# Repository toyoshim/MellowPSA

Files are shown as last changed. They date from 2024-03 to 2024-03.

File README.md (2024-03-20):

# MellowPSA

I/O 1981年6月号に掲載されたPSAを元にして以下の修正を行ったもの

- 入手困難になりつつあるロジックICはまとめてCPLD（MAX7000）で実装した
- RAM制御信号のワンショット化の回路はコンデンサの充電を利用した回路から、同期回路に変更した
- MOVE転送を実行する際、RAM制御だけでなくキャラクターデータ出力もワンショット化した
- 3声化対応のため、I/O 02Hのb6とb7をラッチし、それぞれGATE 1、GATE 2に接続した
- 3声とBEEP音のミックス・増幅回路はM.K WorkshopさんのPSA基板を参考に実装した
- 128キャラクターモートに加え、256キャラクターモードを追加実装した
- OFF、128キャラクターモード、256キャラクターモードはリセットボタンでローテーションで切り替わるように実装した（記事に載っていたリセットボタンでON/OFFにする方法を参考にしている）
- 電源投入時の動作モードを確実にOFFモードに設定するため、電源投入後しばらくLOWに張り付くPON信号をコンデンサのチャージを利用して導入した

注意点
- 現時点でコミットされている基板データはキャラROMの実装位置が2.5ピン分左に寄っているので、新規に作る際には修正してボードを作るべし
- 基板データで用いているSRAMが既に入手困難かもしれない
- そもそもCPLDのMAX7000が入手困難

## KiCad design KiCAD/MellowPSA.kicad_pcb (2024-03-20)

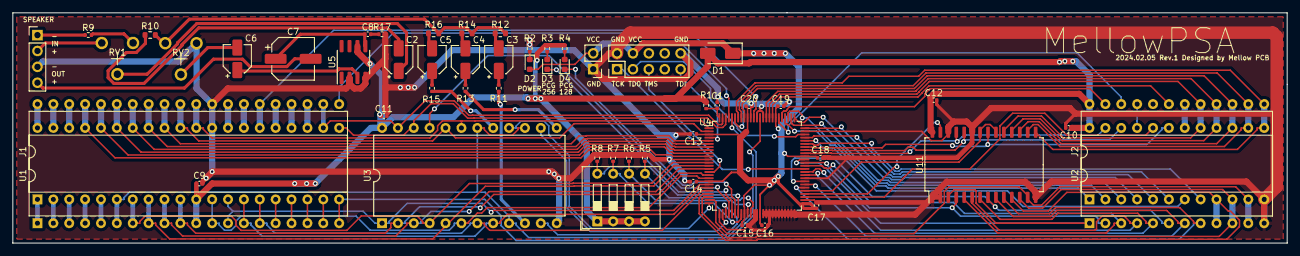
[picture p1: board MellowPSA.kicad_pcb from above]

Board: 2 copper layers, 203.8 x 36.8 mm, 55 parts (0 on the bottom side), 115 nets.

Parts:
C1: 3.3u; C_0402_1005Metric
C2, C3, C4, C5, C6: 10u; CP_Elec_4x5.4
C7: 220u; CP_Elec_6.3x5.4
C8: 0.047u; C_0402_1005Metric
C9, C10, C11, C12, C13, C14, C15, C16, C17, C18, C19, C20: 0.1u; C_0402_1005Metric
D1: D; D_SMA
D2: LED_PWR; LED_0603_1608Metric
D3: LED_256; LED_0603_1608Metric
D4: LED_ON; LED_0603_1608Metric
J1: Z80Socket; DIP-40_W15.24mm
J2: D2716Sock; DIP-24_W15.24mm
J3: JTAG; PinHeader_2x05_P2.54mm_Vertical
J4: PWR; PinHeader_1x02_P2.54mm_Vertical
J5: SP; PinHeader_1x04_P2.54mm_Vertical
R1, R5, R6, R7, R8: 10k; R_0402_1005Metric
R2, R3, R4: 1k; R_0402_1005Metric
R9, R11, R13, R15: 2K; R_0402_1005Metric
R10, R12, R14, R16: 5.6K; R_0603_1608Metric
R17: 10; R_0402_1005Metric
RV1, RV2: 1K; RV-RM-065
SW1: SW_DIP_x04; SW_DIP_SPSTx04_Slide_9.78x12.34mm_W7.62mm_P2.54mm
U1: Z80CPU; DIP-40_W15.24mm
U2: D2716; DIP-24_W15.24mm
U3: 8253; DIP-24_W15.24mm
U4: EPM7128S100(TQFP); TQFP-100_14x14mm_P0.5mm
U5: LM386; SOP-8_3.76x4.96mm_P1.27mm
U11: SRM2B256SLMX; SOIC-28W_8.4x18.7mm_P1.27mm_SRM2B256

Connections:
/A0: J1.30 (A0), U1.30 (A0), U3.19 (A0), U4.1 (I/O)
/A1: J1.31 (A1), U1.31 (A1), U3.20 (A1), U4.2 (I/O)
/A2: J1.32 (A2), U1.32 (A2), U4.5 (I/O)
/A3: J1.33 (A3), U1.33 (A3), U4.6 (I/O)
/A4: J1.34 (A4), U1.34 (A4), U4.7 (I/O)
/A5: J1.35 (A5), U1.35 (A5), U4.8 (I/O)
/A6: J1.36 (A6), U1.36 (A6), U4.9 (I/O)
/A7: J1.37 (A7), U1.37 (A7), U4.10 (I/O)
/A8: J1.38 (A8), U1.38 (A8)
/A9: J1.39 (A9), U1.39 (A9)
/A10: J1.40 (A10), U1.40 (A10)
/A11: J1.1 (A11), U1.1 (A11)
/A12: J1.2 (A12), U1.2 (A12)
/A13: J1.3 (A13), U1.3 (A13)
/A14: J1.4 (A14), U1.4 (A14)
/A15: J1.5 (A15), U1.5 (A15)
/CA0: U2.8, U4.56 (I/O), U11.10 (A0)
/CA1: U2.7, U4.57 (I/O), U11.9 (A1)
/CA2: U2.6, U4.58 (I/O), U11.8 (A2)
/CA3: U2.5, U4.60 (I/O), U11.7 (A3)
/CA4: U2.4, U4.61 (I/O), U11.6 (A4)
/CA5: U2.3, U4.63 (I/O), U11.5 (A5)
/CA6: U2.2, U4.64 (I/O), U11.4 (A6)
/CA7: U2.1, U4.65 (I/O), U11.3 (A7)
/CA8: U2.23, U4.67 (I/O), U11.25 (A8)
/CA9: U2.22, U4.68 (I/O), U11.24 (A9)
/CA10: U2.19, U4.69 (I/O), U11.21 (A10)
/CCS2: J2.18, U2.18
/CCS3: J2.21, U2.21
/CD0: J2.9, U2.9, U4.22 (I/O), U11.11 (D0)
/CD1: J2.10, U2.10, U4.23 (I/O), U11.12 (D1)
/CD2: J2.11, U2.11, U4.24 (I/O), U11.13 (D2)
/CD3: J2.13, U2.13, U4.94 (I/O), U11.15 (D3)
/CD4: J2.14, U2.14, U4.93 (I/O), U11.16 (D4)
/CD5: J2.15, U2.15, U4.92 (I/O), U11.17 (D5)
/CD6: J2.16, U2.16, U4.85 (I/O), U11.18 (D6)
/CD7: J2.17, U2.17, U4.84 (I/O), U11.19 (D7)
/D0: J1.14 (D0), U1.14 (D0), U3.8 (D0), U4.20 (I/O)
/D1: J1.15 (D1), U1.15 (D1), U3.7 (D1), U4.21 (I/O)
/D2: J1.12 (D2), U1.12 (D2), U3.6 (D2), U4.17 (I/O)
/D3: J1.8 (D3), U1.8 (D3), U3.5 (D3), U4.13 (I/O)
/D4: J1.7 (D4), U1.7 (D4), U3.4 (D4), U4.12 (I/O)
/D5: J1.9 (D5), U1.9 (D5), U3.3 (D5), U4.14 (I/O)
/D6: J1.10 (D6), U1.10 (D6), U3.2 (D6), U4.16 (I/O)
/D7: J1.13 (D7), U1.13 (D7), U3.1 (D7), U4.19 (I/O)
/DIPSW0: R5.1, SW1.5, U4.36 (I/O)
/DIPSW1: R6.1, SW1.6, U4.35 (I/O)
/DIPSW2: R7.1, SW1.7, U4.33 (I/O)
/DIPSW3: R8.1, SW1.8, U4.32 (I/O)
/FA0: J2.8, U4.70 (I/O)
/FA1: J2.7, U4.71 (I/O)
/FA2: J2.6, U4.72 (I/O)
/FA3: J2.5, U4.75 (I/O)
/FA4: J2.4, U4.76 (I/O)
/FA5: J2.3, U4.77 (I/O)
/FA6: J2.2, U4.78 (I/O)
/FA7: J2.1, U4.79 (I/O)
/FA8: J2.23, U4.80 (I/O)
/FA9: J2.22, U4.81 (I/O)
/FA10: J2.19, U4.83 (I/O)
/IN+: J5.2, RV1.3
/IN-: J5.1, R9.1
/LED0: D4.1 (K), U4.31 (I/O)
/LED1: D3.1 (K), U4.30 (I/O)
/OUT+: C7.2, J5.4
/PON: C1.2, R1.2, U4.100 (I/O)
/TCK: J3.1, U4.62 (I/O/TCK)
/TDI: J3.9, U4.4 (I/O/TDI)
/TDO: J3.3, U4.73 (I/O/TDO)
/TG0: U3.11 (G0), U4.28 (I/O)
/TG1: U3.14 (G1), U4.27 (I/O)
/TG2: U3.16 (G2), U4.25 (I/O)
/TMS: J3.5, U4.15 (I/O/TMS)
/TO0: R11.1, U3.10 (OUT0)
/TO1: R13.1, U3.13 (OUT1)
/TO2: R15.1, U3.17 (OUT2)
/V_CPLD: C13.1, C14.1, C15.1, C16.1, C17.1, C18.1, C19.1, C20.1, D1.1 (K), D2.2 (A), J3.4, J4.2, U4.3 (VCCIO), U4.18 (VCCIO), U4.34 (VCCIO), U4.39 (VCCINT), U4.51 (VCCIO), U4.66 (VCCIO), U4.82 (VCCIO), U4.91 (VCCINT)
//BUSACK: J1.23 (~BUSACK), U1.23 (~BUSACK)
//BUSRQ: J1.25 (~BUSRQ), U1.25 (~BUSRQ)
//CLK: J1.6 (~CLK), U1.6 (~CLK), U3.9 (CLK0), U3.15 (CLK1), U3.18 (CLK2), U4.87 (INPUT/GCLK1)
//HALT: J1.18 (~HALT), U1.18 (~HALT)
//INT: J1.16 (~INT), U1.16 (~INT)
//IORQ: J1.20 (~IORQ), U1.20 (~IORQ), U4.96 (I/O)
//M1: J1.27 (~M1), U1.27 (~M1)
//MREQ: J1.19 (~MREQ), U1.19 (~MREQ)
//NMI: J1.17 (~NMI), U1.17 (~NMI)
//RAMCS: U4.55 (I/O), U11.20 (~CS), U11.22 (~OE)
//RAMWR: U4.54 (I/O), U11.27 (~WE)
//RD: U1.21 (~RD), U3.22 (~RD), U4.98 (I/O)
//RD_MB: J1.21 (~RD), U4.97 (I/O)
//RESET: J1.26 (~RESET), U1.26 (~RESET), U4.89 (INPUT/GCLRn)
//RFSH: J1.28 (~RFSH), U1.28 (~RFSH)
//ROMCS: U2.20, U4.53 (I/O)
//TCS: U3.21 (~CS), U4.29 (I/O)
//WAIT: J1.24 (~WAIT), U1.24 (~WAIT)
//WR: J1.22 (~WR), U1.22 (~WR), U3.23 (~WR), U4.99 (I/O)
GND: C1.1, C9.2, C10.2, C11.2, C12.2, C13.2, C14.2, C15.2, C16.2, C17.2, C18.2, C19.2, C20.2, J1.29 (GND), J2.12, J3.2, J3.10, J4.1, J5.3, R2.1, R5.2, R6.2, R7.2, R8.2, R17.2, RV2.1, U1.29 (GND), U2.12, U3.12 (GND), U4.11 (GNDIO), U4.26 (GNDIO), U4.37 (I/O), U4.38 (GNDINT), U4.40 (I/O), U4.41 (I/O), U4.42 (I/O), U4.43 (GNDIO), U4.44 (I/O), U4.45 (I/O), U4.46 (I/O), U4.47 (I/O), U4.48 (I/O), U4.49 (I/O), U4.50 (I/O), U4.52 (I/O), U4.59 (GNDIO), U4.74 (GNDIO), U4.86 (GNDINT), U4.88 (INPUT/OE1), U4.90 (INPUT/OE2/GCLK2), U4.95 (GNDIO), U5.2 (-), U5.4 (GND), U11.1 (A14), U11.2 (A12), U11.14 (GND), U11.23 (A11), U11.26 (A13)
unnamed: C2.1, RV1.2
unnamed: C2.2, R10.1
unnamed: C3.1, R11.2
unnamed: C3.2, R12.1
unnamed: C4.1, R13.2
unnamed: C4.2, R14.1
unnamed: C5.1, R15.2
unnamed: C5.2, R16.1
unnamed: C6.2, RV2.2
unnamed: C7.1, C8.1, U5.5
unnamed: C8.2, R17.1
unnamed: D2.1 (K), R2.2
unnamed: D3.2 (A), R3.2
unnamed: D4.2 (A), R4.2
unnamed: R9.2, RV1.1
unnamed: R10.2, R12.2, R14.2, R16.2, RV2.3
unnamed: C6.1, U5.3 (+)
VCC: C9.1, C10.1, C11.1, C12.1, D1.2 (A), J1.11 (VCC), J2.24, R1.1, R3.1, R4.1, SW1.1, SW1.2, SW1.3, SW1.4, U1.11 (VCC), U2.24, U3.24 (VCC), U5.6 (V+), U11.28 (VCC)

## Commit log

2024-03-20 move KiCAD projects into KiCAD directory
    [MellowPSA.dsn, MellowPSA.kicad_pcb, MellowPSA.kicad_sch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]
2024-03-20 remove unnecessary files
    [MellowPSA.dsn, MellowPSA_.kicad_sch]
